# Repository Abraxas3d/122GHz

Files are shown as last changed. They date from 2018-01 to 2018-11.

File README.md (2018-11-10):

# 122GHz for Amateur Radio
Here are 122GHz dishs, feed, and sub reflectors that can be 3D printed and metallized (or machined). 

The hyperbolic solid sub reflector is also at https://www.thingiverse.com/thing:2750924

The parabolic dish is also at https://www.thingiverse.com/thing:2751650

The design presented at Microwave Update 2018 is in the MUD_2018_demo folder.

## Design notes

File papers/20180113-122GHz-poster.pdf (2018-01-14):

## 3D Printing a 122GHz Amateur Radio Station Progress Report 15 January 2018

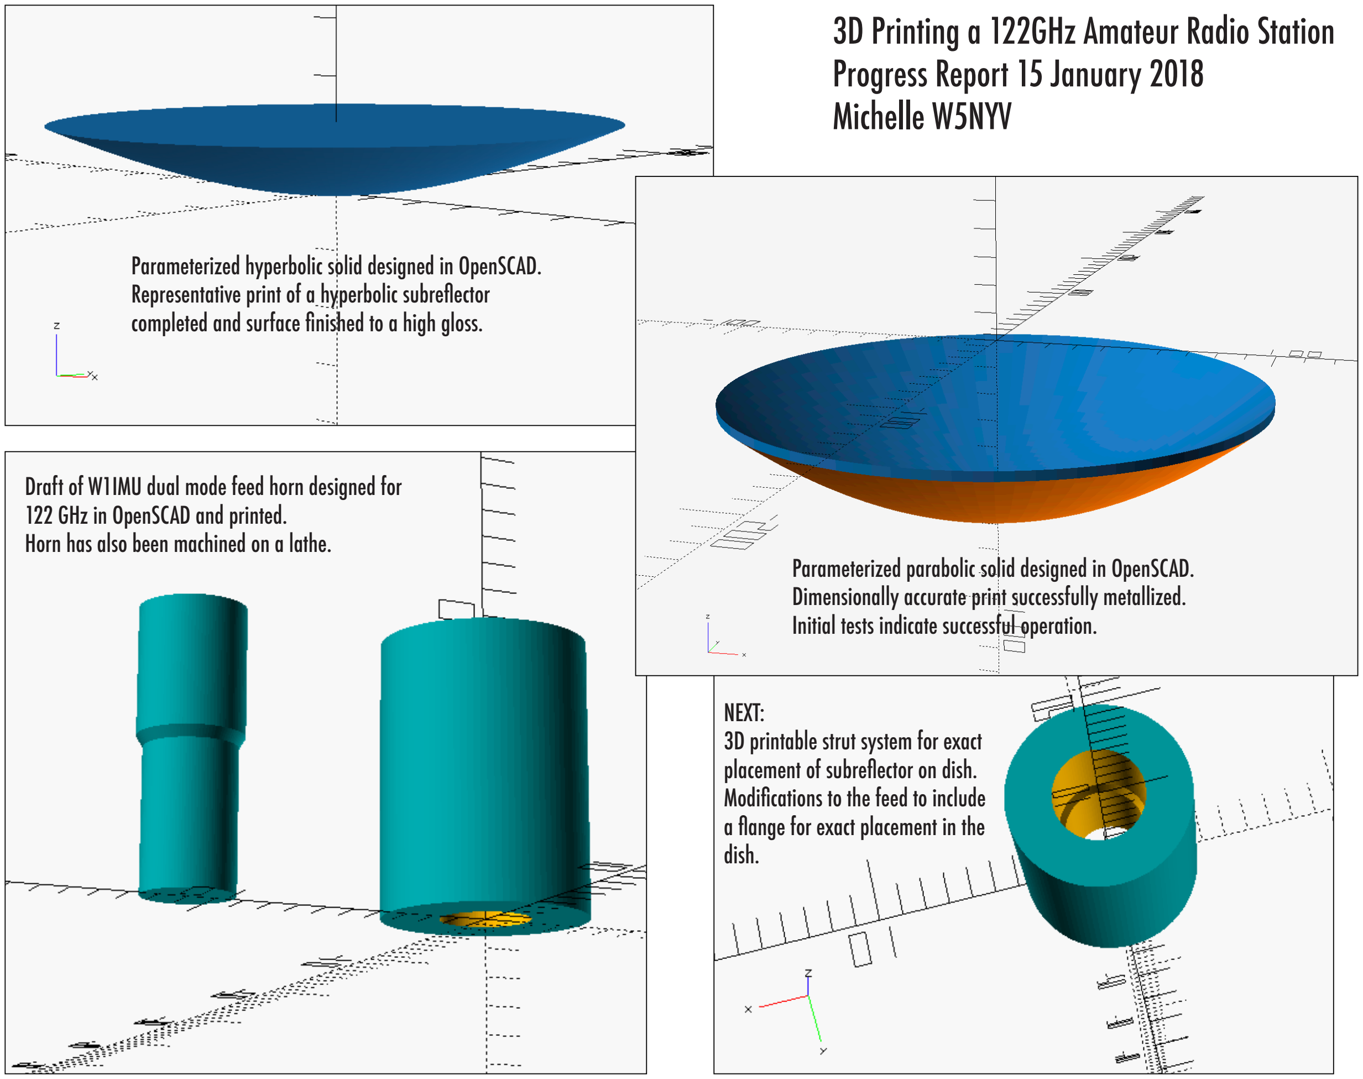
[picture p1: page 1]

## Michelle W5NYV

Parameterized hyperbolic solid designed in OpenSCAD. Representative print of a hyperbolic subreflector completed and surface finished to a high gloss.

Parameterized parabolic solid designed in OpenSCAD. Dimensionally accurate print successfully metallized. Initial tests indicate successful operation.

Draft of W1IMU dual mode feed horn designed for 122 GHz in OpenSCAD and printed.
Horn has also been machined on a lathe.

NEXT:
3D printable strut system for exact placement of subreflector on dish. Modifications to the feed to include a flange for exact placement in the dish.

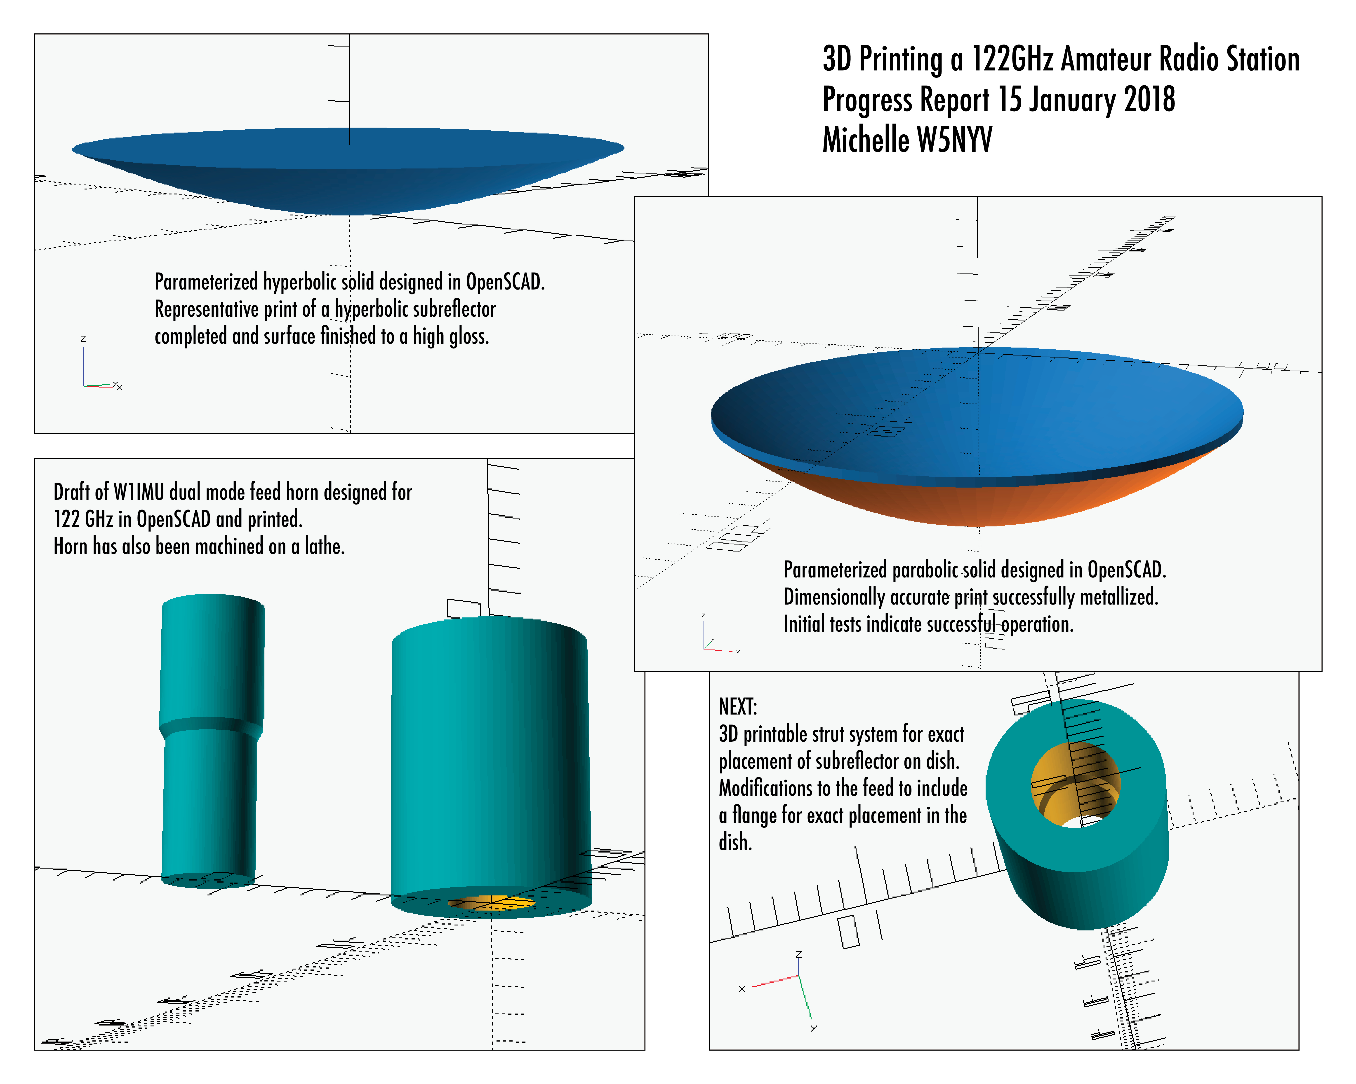
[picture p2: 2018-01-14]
papers/20180113-122GHz-poster.jpg

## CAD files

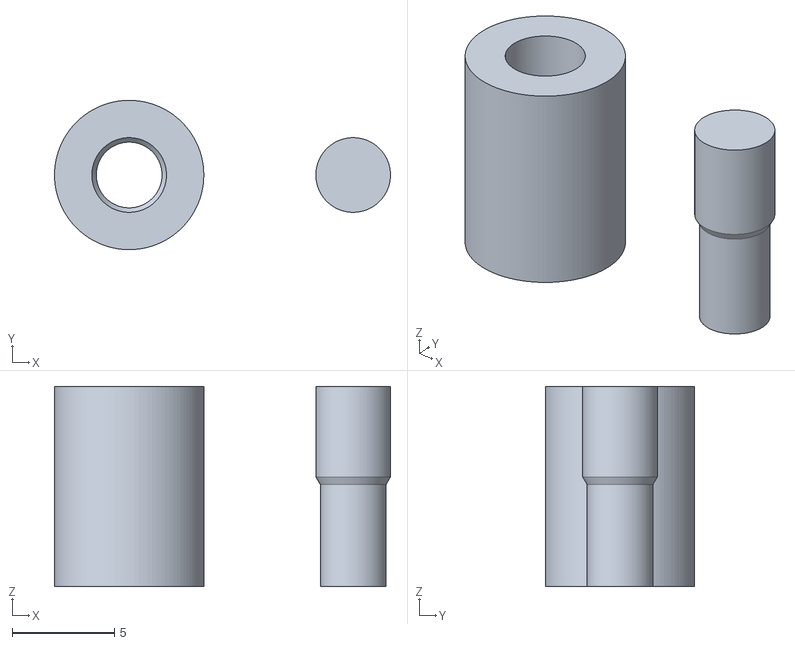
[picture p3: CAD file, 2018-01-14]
feed_experiments/dual-mode-W2IMU-feedhorn.stl
16.5 x 7.32 x 9.82

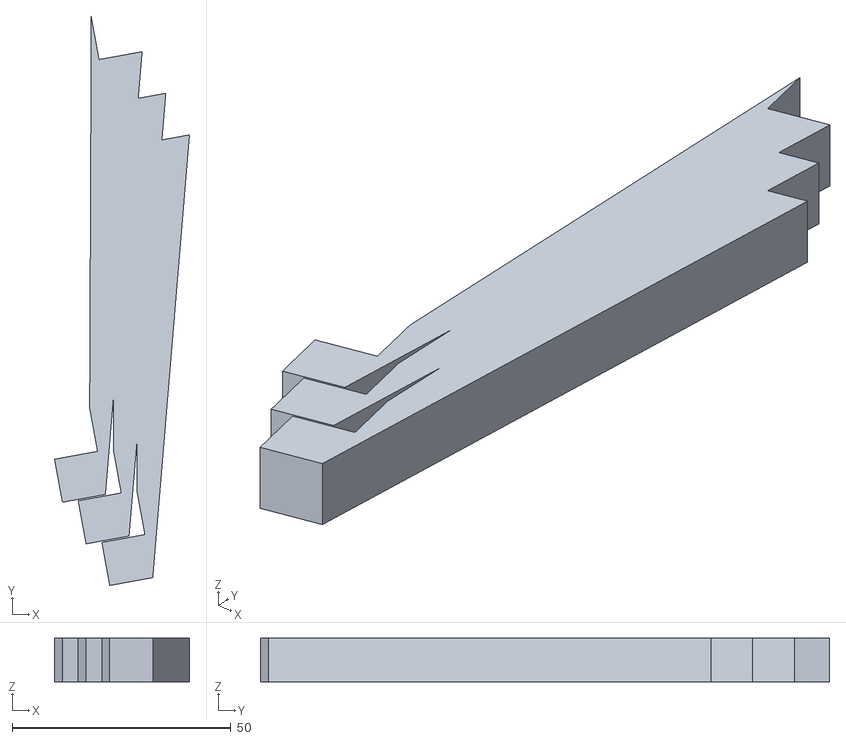
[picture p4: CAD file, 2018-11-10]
MUD_2018_demo/struts.stl
30.9 x 130.0 x 10.0

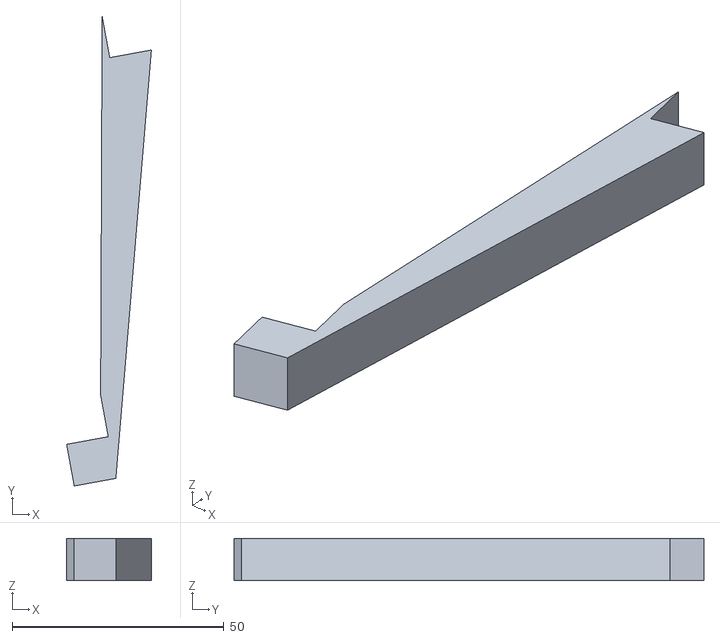
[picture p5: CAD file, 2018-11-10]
MUD_2018_demo/UM2_struts.stl
20.0 x 111.0 x 10.0

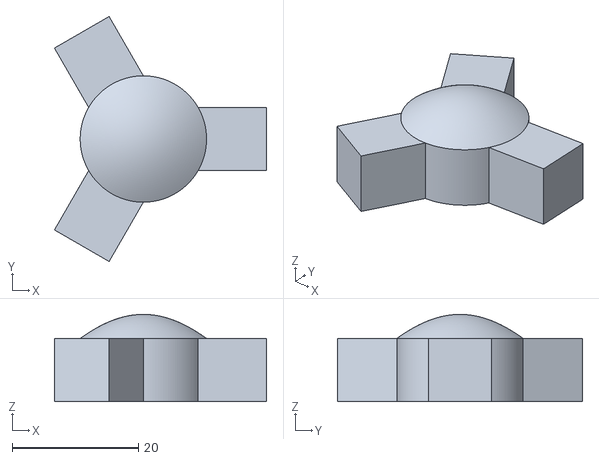
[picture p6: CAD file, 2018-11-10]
MUD_2018_demo/Cassegrain_Dish_120GHz_secondary.stl
33.6 x 38.8 x 13.8

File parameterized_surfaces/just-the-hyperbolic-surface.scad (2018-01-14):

//Hyperbolic Solid in OpenSCAD
//by Michelle Thompson @abraxas3d

//A hyperbola is the set of all points where the difference 
//in the distance from intstwo fixed po is a constant. 

//What we are after here is the positive half of a hyperbola.
//We then rotate it around its transverse axis in order
//to make a hyperbolic surface.

//This hyperbolic surface is then 3D printed in order to
//provide a prototype subreflector for a microwave cassegrain
//antenna system for radio experimentation. 

//equation for a hyperbola is (x^2)/(a^2)  -  (y^2)/(b^2)   =   1
// x = a sec(angle)
// y = b tan(angle)
// angle varies from 0 to pi/2

//f = 75 = 2*c. c = 75/2. get this from the dish diameter
c = 75/2;
echo("c is ", c);

//a and b are the dimensions of the box that defines the
//asymptotes of the hyperbolic curve. 

b = 200*(1/16); //radius set to 1/10 of dish diameter? to get diameter to be 1/5?
echo("b is ", b);

a = sqrt(c*c - b*b); //if we have b and c, we can calculate a from geometry of hyperbola
echo("a is ", a);


//resolution variable in OpenSCAD. Higher numbers mean smoother surface.
$fn = 200;

max_angle = 45; //calculate all the hyperbola!
angle_resolution = 0.5; //calculate at a good resolution

//granularity should match the length of the polygon vector
//before we add the two finishing points that complete a closed curve.
granularity = max_angle/angle_resolution;


//Depending on the behavior desired, one might want either
//a vertical or a horizontal hyperbolic curve.
//choose which one here.
//set horizontal to true for horizontal (creates the right shape when rotated).
//set horizontal to false for vertical (creates an interesting shape when rotated).
horizontal = true;


//For horizontal case:
//we are defining functions that make a vector of points. 
//each point is a vector in and of itself in the form [x,y]
//the vector of points follows a horizontal hyperbolic curve.
//the independent variable is the angle from 0 to max_angle.
//we use concat() to build the vector of points as long as
//we do not exceed the max_angle. we increment by angle_resolution
//and then calculate a new set of points. 
//secant is the reciprocal of cosine
function horiz_hyper(angle) = angle < max_angle ? concat([[b*tan(angle), a*(1/(cos(angle)))]], horiz_hyper(angle + angle_resolution)) : [];



//For vertical case:
//we are defining functions that make a vector of points. 
//each point is a vector in and of itself in the form [x,y]
//the vector of points follows a vertical hyperbolic curve.
//the independent variable is the angle from 0 to max_angle.
//we use concat() to build the vector of points as long as
//we do not exceed the max_angle. we increment by angle_resolution
//and then calculate a new set of points. 
//secant is the reciprocal of cosine
function vert_hyper(angle) = angle < max_angle ? concat([[ a*(1/(cos(angle))) , b*tan(angle)]], vert_hyper(angle + angle_resolution)) : [];




if (horizontal == true) {
    
//we have a hyperbolic curve, but it needs to be closed so
//that we can turn it into a polygon and then rotate to get a solid.

//uncomment this block for checks
/*
//check the length of the vector
echo(len(horiz_hyper(0)));

//check the last entry
echo(horiz_hyper(0)[granularity - 1]);

//check the y value from the last set of points. 
echo(horiz_hyper(0)[granularity - 1][1]);

//check entire list of points.
echo(horiz_hyper(0));
*/

//get the y value from the last set of points.
replace_horiz = horiz_hyper(0)[granularity - 1][1];

//add two points to the curve to close it, using concat().
//first, stay at current y value, but set x to zero so that
//we come across to the y axis to make the top of the polygon.
//then, drop straight down to where we started. 
full_set_horiz = concat(horiz_hyper(0), [[0, replace_horiz]], [[0,a]]);

//show the polygon we created.
/*
translate([0, 0, 0]) polygon(full_set_horiz);
*/


difference() {
//use rotate_extrude to rotate the 2d polygon and make it a 3d shape.
translate([0, 0, 0]) rotate_extrude(angle = 360, convexity = 10) polygon(full_set_horiz);

//here's a base so we can stick struts on.
base_thickness = 100;
translate([0, 0, (c+a)/2+(c-a)]) cylinder(h = base_thickness, r1 = b, r2 = b, center=false);


translate([-5,0,(c+a)/2+(c-a)-0.5])
{
    linear_extrude(0.5)
        text("12.5%", size = 2);
}

}



} else {
    
//we have a hyperbolic curve, but it needs to be closed so
//that we can turn it into a polygon and then rotate to get a solid.

//uncomment this block for checks
/*
//check the length of the vector
echo(len(vert_hyper(0)));

//check the last entry
echo(vert_hyper(0)[granularity - 1]);

//check the x value from the last set of points.
echo(vert_hyper(0)[granularity - 1][0]);
    
//check entire list of points.
echo(vert_hyper(0));
*/
    
//get the x value from the last set of points.
replace_vert = vert_hyper(0)[granularity - 1][0];
    
//add two points to the curve to close it, using concat().
//first, stay at current x value, but set y to zero so that
//we come across to the x axis to make the top of the polygon.
//then, drop straight down to where we started.
full_set_vert = concat(vert_hyper(0), [[replace_vert, 0]], [[a,0]]);

//show the polygon we created.
/*
translate([0, 0, 0]) polygon(full_set_vert);
*/
    
//use rotate_extrude to rotate the 2d polygon and make it a 3d shape.
rotate_extrude(angle = 360, convexity = 10) translate([0, 0, 0]) polygon(full_set_vert);

}


//Next, add a strut to connect to the parabolic reflector.
//W1GHZ says, "If you are using linear polarization, a single strut would
//be worst in the E-plane (horizontal for horizontal polarization)."

//So let's make it adjustable.

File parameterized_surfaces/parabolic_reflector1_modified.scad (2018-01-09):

/*
parabolic_reflector module
by Kwikius
http://forums.reprap.org/read.php?340,333400,336285#msg-336285
creates a parabolic_reflector with a flat base
centered on its focus
 dia : float //  diameter of the reflector
 f   : float  // focal length
 numx : integer  // the number of points to plot on the parabola
 numr : integer // radial number of segments
 base : float // thickness of the base.
*/
module parabolic_reflector(dia, f, numx, numr, base_thickness)
{
    // from the focus determine the quadratic constant for y = a x^2 + base_thickness;
    a = 1 / (4 * f);
    // from diameter and required curve points determine the xdecrement
    // for each iteration of the parabola_pts function below
    xdecr = dia / (2 * numx);
    /*
     parabola_pts
     recursive function that builds the basic polygon points sequence
     Each iteration adds a point until the terminating condition is reached
     N.B. If you set the initial  point to [0,0]. works ok in draft but CGAL barfs
      x : float // the max x position
    */
    function parabola_pts(x) =
        (x <= 0.001)
        ?[[0.001,-f]] //BUG!x cannot be [[0,0][ for cgal to work ok in rotate_extrude
        :concat(parabola_pts(x-xdecr),[[x,a * x * x - f ]]);

    // create the 3d shape from the polygon we created
    rotate_extrude(convexity = 10, $fn = numr) {
        // before the rotate_extrude add 2 points to the polygon
        // again using the builtin concat function
        // which makes the flat base
        polygon(points =
                    concat([[dia/2,-(f + base_thickness)],[0.001,-(f + base_thickness)]],
                           parabola_pts(dia / 2) )
               ) ;
    }
}

//----------

// use the flag variables to change whats shown to show various features...
// N.B. if you cant see anything on changing parameters try zooming out!

// set show_offset_reflector to false to show the reflector before chopping out only the offset part
// warning set this to true and may take a while to compile!
show_offset_reflector = false;
//show_basic_object (dont care if show_offset_reflector == true)
// otherwise set to true to see just the basic module with the above parameters
show_basic_object = false;

// Use the module to create an object
// fill in some parameters with values dependent on the object
diameter = show_offset_reflector?820:show_basic_object?200:200;  // mm
//diameter = show_basic_object?200:show_offset_reflector?600:100;  // mm
num_x_points = show_offset_reflector?100:200; // more better detail but slower render
num_r_points = show_offset_reflector?100:100; // more better detail but slower render
//60mm for focal length gives f/D of 0.3
focal_length = show_offset_reflector?50:show_basic_object?75:60; // mm 
base_thickness = 5; // mm
material_thickness = 2; //mm

//-------
rotate([0,0,45])
if (show_offset_reflector == false) {

    if ( show_basic_object == true) {
        parabolic_reflector(diameter,focal_length,num_x_points,num_r_points,base_thickness);
    } else {
        // subtract a nearly similar reflector to give a thin wall reflector
        difference() {
            parabolic_reflector(diameter,focal_length,num_x_points,num_r_points,base_thickness);
            //subtracting a reflector with a very slightly bigger diameter . This prevents very thin walls due to floating point calcs)
            // The material thickness is the difference in focal length
            // between the original and the subtrahend ( because the object is centered on the focus)
            parabolic_reflector(diameter + 0.1,focal_length + material_thickness,num_x_points,num_r_points,base_thickness);
        }
    }
} else
{
// create an offset reflector by intersecting an offset cylinder with the reflector
// (Useful on a small reflector to prevent the antenna or detector from masking the reflector)

    intersection()
    {
        union() {
            difference() {
                parabolic_reflector(diameter,focal_length,num_x_points,num_r_points,base_thickness);
                //subtract a reflector with a very slightly bigger diameter
                // The material thickness is the difference in focal length
                // between the original and the subtrahend
                parabolic_reflector(diameter + 0.1,focal_length + material_thickness,num_x_points,num_r_points,base_thickness);
            }
        }

        translate([0,70,0]) {
           rotate([45,0,0])
            scale([1.25,.75,1]){// elliptical cylinder
            cylinder(d = 125,h = 200,center = true, $fn = 100);
				}
        }
    }
}
// Put a sphere at the focus to show where the focus is
//sphere(d=10,center = true);



//Use WR-7 waveguide flange
// width 1.651mm	height 0.0325 0.8255mm
waveguide_width = 1.651;
waveguide_height = 0.8255;

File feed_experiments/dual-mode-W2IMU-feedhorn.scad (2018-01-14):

//122GHz feedhorn
//based on W1GHZ's Feeds for Parabolic Dish Antennas, Chapter 6
//This is a version of the W2IMU Dual-Mode Feed
//flare half angle recommendation from W1GHZ

a = 3.22; //mm
b = 3.66; //mm
c = 4.44; //mm
half_angle = 30; //degrees
waveguide_length = 5; //mm
flare_length = ((b/2 - a/2)/tan(half_angle)); //mm
outer_diameter = b; //mm
over_there = 3*b; //mm

$fn = 100;





difference()
{
//outer cylinder to subtract from
cylinder(h= (waveguide_length + flare_length + c), r1=outer_diameter, r2=outer_diameter, center=false);

//inner radius of input waveguide
cylinder(h= waveguide_length, r1=a/2, r2=a/2, center=false);

//inner radius of flare
translate([0,0,waveguide_length]) cylinder(h=flare_length, r1=a/2, r2=b/2, center=false);

//inner radius of output waveguide
translate([0,0,waveguide_length + flare_length]) cylinder(h= c, r1=b/2, r2=b/2, center=false);
}


//make a drawing of what the interior radii look like

//inner radius of input waveguide
translate([over_there, 0, 0]) cylinder(h= waveguide_length, r1=a/2, r2=a/2, center=false);

//inner radius of flare
translate([over_there,0,waveguide_length]) cylinder(h=flare_length, r1=a/2, r2=b/2, center=false);

//inner radius of output waveguide
translate([over_there,0,waveguide_length + flare_length]) cylinder(h= c, r1=b/2, r2=b/2, center=false);

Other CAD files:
MUD_2018_demo/Cassegrain_Dish_120GHz.scad

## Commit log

2017-09-18 the OpenSCAD script
    [parabolic_reflector1_modified.scad]
2018-01-09 adding the subreflector OpenSCAD file
    [just-the-hyperbolic-surface.scad]
2018-01-09 note for translate of Final Position
    [just-the-hyperbolic-surface.scad]
2018-01-09 add STL, name
    Added STL and name
    [just-the-hyperbolic-surface.scad]
2018-01-09 STL for parabolic dish
2018-01-09 added note about f/D
    [parabolic_reflector1_modified.scad]
2018-01-14 draft of W1IMU feed horn
    [dual-mode-W2IMU-feedhorn.scad, dual-mode-W2IMU-feedhorn.stl, just-the-hyperbolic-surface.scad]
2018-11-10 re-arranged folders
    [Cassegrain_Dish_120GHz.scad, Cassegrain_Dish_120GHz_secondary.stl, UM2_struts.stl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]
